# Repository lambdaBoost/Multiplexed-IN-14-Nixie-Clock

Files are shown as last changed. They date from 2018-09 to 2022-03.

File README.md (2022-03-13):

# Multiplexed IN-14 Nixie Clock
PCB design and coding for a slimline nixie clock using multiplexing of 6 IN-14 nixie tubes. Powered by a standard Micro USB.

[*Youtube video discussing principles of operation and showing it in action*](https://www.youtube.com/watch?v=PkoFvk80PU8)

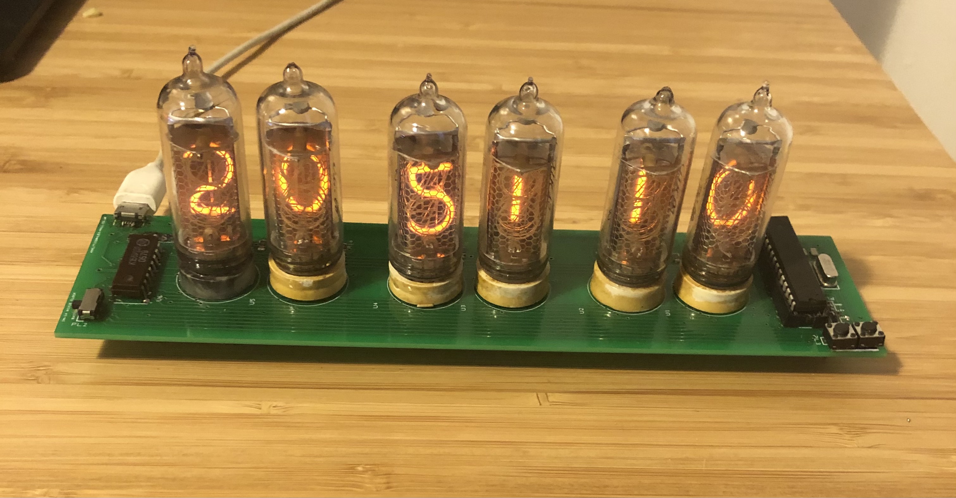
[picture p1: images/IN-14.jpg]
Prototype Build


## Principle of Operation.
This clock uses a Soviet-era Nixie driver to drive 6 Soviet-era Nixie tubes. The aim of this project was to produce a slimline and aesthetically pleasing clock for a minimal cost. To achieve this, the tubes are multiplexed meaning only a single driver chip is required. Multiplexing is not complicated - it is simply the act of switching the tubes on and off at a high enough frequency that the human eye cannot detect the flicker. By only having one tube on at a given time, only one driver chip is needed, less microprocessor pins are needed and the power consumption is reduced.

Rather than attempting to rectify mains voltage, the unit is powered from a +5V USB. While less efficient, this removes the danger of dealing with mains voltage.

## How to build your own
For those wanting to just build a clock and not worry about the details, just follow these steps:

* Gather materials given in the bill of materials (in the PCB design folder).
* Gather the additional materials listed below.
* Have the PCB manufactured with the gerber files provided. You'll need to choose whether to go with the original pcb design which has some issues, or the rev2 where these are fixed but it's untested.
* Solder the components to the PCB. Be careful with the nixie tubes - let them cool down between soldering each pin.
* Upload either the software_rtc.ino' script to your Arduino Uno if you don't have an rtc module installed. If you did but an rtc module, upload the 'hardware_rtc.ino' script.
* Remove the chip from the Arduino and insert into the socket on the pcb.
* Plug in a microUSB and set the time using the buttons. Push both to reset the seconds, and hold both to adjust the brightness.

## PCB design

**Note there are two seperate designs - the original and the rev 2. The original is tested and pictured above sitting on my desk (with some minor modifications to connect the buttons and add decoupling capacitors and add a switch which was not included on the original schematic). The rev 2 fixes some issues discussed below but I have not had this version manufactured so it is currently untested but should work fine providing I didn't make any mistakes fixing up the issues.**

The 'PCB design' directory contains all the files necessary for production of the PCB. For those just wanting to make the clock, the gerber files alone are sufficient - they can be sent to your PCB manufacturer of choice.

For anyone wanting to improve on the design, which is not perfect, the sehematic and PCB files are also included.

The bill of materials is also included. In addition to the components stated, you will need:
* 6 X IN-14 nixie tubes 
* a single K155ID1 nixie driver. A 74141 driver may also be used but these are rare/expensive and offer no real benefit over the former (the K155ID1 is a Russian copy of the 74141). 
* A nixie power supply. One that can provide 170V from a 5V DC source is necessary - plenty are available online but check the order of the output pins - the one I used was cheap but seems to work fine for now. It is available [here]( https://bit.ly/2IDABvU).  
* (OPTIONAL). If you want the clock to keep time when it is unplugged you'll need a DS1307 RTC module like [this](https://www.amazon.co.uk/DS1307-AT24C32-Clock-module-board/dp/B00CWX6UXY). Again, check that the pins are in the same order as that shown. You need them in the order GND,VCC,SDA,SCL. If you want more accurate timekeeping, a DS3231 would be better but you'll have to make a couple of monir changes to the code.
* A USB -> micro USB cable to power it.
* Either an Arduino UNO, or a ISP capable of programming the Atmega328p chip.

It would be possible to reduce the profile of the PCB further by using a SMD microprocessor and an alternate driver chip for the tubes. However, the configuration used here is far easier to program and install. I also personally like the aesthetics of the DIP chips next to the Nixie tubes.

## Arduino code
As the unit uses an ATMEGA328p DIP chip, it can be programmed using an arduino UNO. Simply upload the code to your UNO, remove the DIP chip and insert it into the holder on the PCB - that's it, no ISP programmer needed.

The code required depends on whether you have a DS1307 (or other RTC) module installed:
* If you have a ds1307 module installed, upload the code at nixie_code/hardware_rtc
* If you don't, upload the code at nixie_code/software_rtc

I won't go into details here since the code is commented.

## Improvements
As I designed this PCB a few years ago, and I'm not an electronics engineer, it has some issues which I should really fix. I'll keep these updated in the project issues.

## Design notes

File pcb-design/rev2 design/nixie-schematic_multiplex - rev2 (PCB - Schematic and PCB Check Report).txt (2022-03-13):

Schematic and PCB Check Report
------------------------------

Report Written:     Sunday, March 13, 2022
Design Path:        C:\Users\Alex\Documents\personal-projects\Multiplexed-IN-14-Nixie-Clock\pcb-design\rev2 design\nixie-schematic_multiplex - rev2.pcb
Design Title:       
Created:            13/09/2018 13:02:49
Last Saved:         13/03/2022 22:27:51
Editing Time:       9024 min
Units:              mm (precision 1)

Checking integrity of Schematic "C:\Users\Alex\Documents\personal-projects\Multiplexed-IN-14-Nixie-Clock\pcb-design\rev2 design\nixie-schematic_multiplex - rev2.sch" with PCB "C:\Users\Alex\Documents\personal-projects\Multiplexed-IN-14-Nixie-Clock\pcb-design\rev2 design\nixie-schematic_multiplex - rev2.pcb"
====================================================================================================================================================================================================================================================================================================================

End Of Report.

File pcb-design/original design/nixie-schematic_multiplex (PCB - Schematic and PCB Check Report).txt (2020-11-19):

Schematic and PCB Check Report
------------------------------

Report Written:     Thursday, November 19, 2020
Design Path:        C:\Users\Alex\Documents\personal-projects\Multiplexed-IN-14-Nixie-Clock\pcb-design\original design\nixie-schematic_multiplex.pcb
Design Title:       
Created:            13/09/2018 13:02:49
Last Saved:         19/11/2020 09:54:43
Editing Time:       8970 min
Units:              mm (precision 1)

Checking integrity of Schematic "C:\Users\Alex\Documents\personal-projects\Multiplexed-IN-14-Nixie-Clock\pcb-design\original design\nixie-schematic_multiplex.sch" with PCB "C:\Users\Alex\Documents\personal-projects\Multiplexed-IN-14-Nixie-Clock\pcb-design\original design\nixie-schematic_multiplex.pcb"
==============================================================================================================================================================================================================================================================================================================

End Of Report.

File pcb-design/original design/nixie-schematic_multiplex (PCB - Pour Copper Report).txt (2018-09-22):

Pour Copper Report
------------------

Report Written:     Tuesday, September 18, 2018
Design Path:        C:\Users\ahall\Documents\projects\nixie-clock\nixie-clock\designspark-nixie\nixie-schematic_multiplex2.pcb
Design Title:       
Created:            13/09/2018 14:02:49
Last Saved:         18/09/2018 20:24:57
Editing Time:       7505 min
Units:              mm (precision 1)

End Of Report.

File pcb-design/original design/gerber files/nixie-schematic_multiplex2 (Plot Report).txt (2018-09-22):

Plot Report
-----------

Report Written:     Monday, September 17, 2018
Design Path:        C:\Users\ahall\Documents\projects\nixie-clock\nixie-clock\designspark-nixie\nixie-schematic_multiplex2.pcb
Design Title:       
Created:            13/09/2018 14:02:49
Last Saved:         17/09/2018 21:49:33
Editing Time:       6154 min
Units:              mm (precision 1)

Device Settings
===============

Gerber Settings
===============

    Leading zero suppression.
    G01 assumed throughout.
    Line termination <*> <CR> <LF>.
    3.5 format absolute inches.

    Format commands defined in Gerber file.
    Aperture table defined in Gerber file.
    Hardware arcs allowed.

Drill Settings
==============

    Excellon Format 1    Format 3.5 absolute in inches.
    Leading zero suppression.

Plots Output
============

Gerber Output
=============

C:\Users\ahall\Documents\projects\nixie-clock\nixie-clock\designspark-nixie\nixie-schematic_multiplex2 - Top Documentation.gbr

    Layers:
    ---------------------
    Top Documentation

    D-Code Shape  (thou)
    -----------------------
    D10    Round 1.97

Gerber Output
=============

C:\Users\ahall\Documents\projects\nixie-clock\nixie-clock\designspark-nixie\nixie-schematic_multiplex2 - Top Silkscreen.gbr

    Layers:
    ------------------
    Top Silkscreen

    D-Code Shape  (thou)
    -----------------------
    D12    Round 1.00
    D14    Round 7.87
    D15    Round 5.00
    D16    Round 10.00

Gerber Output
=============

C:\Users\ahall\Documents\projects\nixie-clock\nixie-clock\designspark-nixie\nixie-schematic_multiplex2 - Top Copper.gbr

    Layers:
    --------------
    Top Copper

    D-Code Shape  (thou)
    ----------------------------------------------
    D18    Square 44.61
    D19    Round 44.61
    D71    Square 60.00
    D20    Round 44.49
    D25    Round 60.00
    D27    Round 56.00
    D28    Round 50.00
    D29    Round 48.00
    D72    Round 15.00
    D86    Oval 60.00 X 110.00  Rotation 90
    D87    Rectangle 23.62 X 41.34  Rotation 90
    D88    Rectangle 27.56 X 39.37
    D89    Rectangle 45.28 X 66.93
    D90    Rectangle 39.37 X 68.90
    D91    Rectangle 15.75 X 53.15  Rotation 90
    D92    Rectangle 47.24 X 51.18  Rotation 90
    D93    Rectangle 74.80 X 84.65
    D94    Rectangle 40.16 X 71.65
    D95    Rectangle 41.34 X 70.87  Rotation 90

Gerber Output
=============

C:\Users\ahall\Documents\projects\nixie-clock\nixie-clock\designspark-nixie\nixie-schematic_multiplex2 - Top Copper (Resist).gbr

    Layers:
    --------------
    Top Copper

    D-Code Shape  (thou)
    ----------------------------------------------
    D73    Square 54.61
    D74    Round 54.61
    D76    Square 70.00
    D77    Round 54.49
    D82    Round 70.00
    D96    Oval 70.00 X 120.00  Rotation 90
    D97    Rectangle 33.62 X 51.34  Rotation 90
    D98    Rectangle 37.56 X 49.37
    D99    Rectangle 55.28 X 76.93
    D100   Rectangle 49.37 X 78.90
    D101   Rectangle 25.75 X 63.15  Rotation 90
    D102   Rectangle 57.24 X 61.18  Rotation 90
    D103   Rectangle 84.80 X 94.65
    D104   Rectangle 50.16 X 81.65
    D105   Rectangle 51.34 X 80.87  Rotation 90

Gerber Output
=============

C:\Users\ahall\Documents\projects\nixie-clock\nixie-clock\designspark-nixie\nixie-schematic_multiplex2 - Top Copper (Paste).gbr

    Layers:
    --------------
    Top Copper

    D-Code Shape  (thou)
    ----------------------------------------------
    D106   Rectangle 19.62 X 37.34  Rotation 90
    D107   Rectangle 23.56 X 35.37
    D108   Rectangle 41.28 X 62.93
    D109   Rectangle 35.37 X 64.90
    D110   Rectangle 11.75 X 49.15  Rotation 90
    D111   Rectangle 43.24 X 47.18  Rotation 90
    D112   Rectangle 70.80 X 80.65
    D113   Rectangle 36.16 X 67.65
    D114   Rectangle 37.34 X 66.87  Rotation 90

Gerber Output
=============

C:\Users\ahall\Documents\projects\nixie-clock\nixie-clock\designspark-nixie\nixie-schematic_multiplex2 - Bottom Copper.gbr

    Layers:
    -----------------
    Bottom Copper

    D-Code Shape  (thou)
    ------------------------------------------
    D18    Square 44.61
    D19    Round 44.61
    D71    Square 60.00
    D20    Round 44.49
    D25    Round 60.00
    D27    Round 56.00
    D28    Round 50.00
    D29    Round 48.00
    D72    Round 15.00
    D86    Oval 60.00 X 110.00  Rotation 90

Gerber Output
=============

C:\Users\ahall\Documents\projects\nixie-clock\nixie-clock\designspark-nixie\nixie-schematic_multiplex2 - Bottom Copper (Resist).gbr

    Layers:
    -----------------
    Bottom Copper

    D-Code Shape  (thou)
    ------------------------------------------
    D73    Square 54.61
    D74    Round 54.61
    D76    Square 70.00
    D77    Round 54.49
    D82    Round 70.00
    D96    Oval 70.00 X 120.00  Rotation 90

Gerber Output
=============

C:\Users\ahall\Documents\projects\nixie-clock\nixie-clock\designspark-nixie\nixie-schematic_multiplex2 - Bottom Copper (Paste).gbr

    Layers:
    -----------------
    Bottom Copper

    D-Code Shape  (thou)
    -----------------------

NC Drill Output
===============

C:\Users\ahall\Documents\projects\nixie-clock\nixie-clock\designspark-nixie\nixie-schematic_multiplex2 - Drill Data - [Through Hole].drl

    Output:
    ---------------------------
    Plated Round Drill Holes
    Plated Slots
    Plated Board Outlines

    Tool  Size           Count   ID
    --------------------------------------
    T001  0.02400 inches 128   K
    T002  0.02480 inches 2     D
    T003  0.02886 inches 44    A
    T004  0.03200 inches 35    J
    T005  0.03500 inches 12    C
    T006  0.03543 inches 78    H
    --------------------------------------
    Total                299
    --------------------------------------

C:\Users\ahall\Documents\projects\nixie-clock\nixie-clock\designspark-nixie\nixie-schematic_multiplex2 - Drill Data - [Through Hole] (Unplated).drl

    Output:
    -----------------------------
    Unplated Round Drill Holes
    Unplated Slots
    Unplated Board Outlines

    Tool  Size           Count   ID
    --------------------------------------
    T001  0.02500 inches 1
    --------------------------------------
    Total                1
    --------------------------------------

Gerber Output
=============

C:\Users\ahall\Documents\projects\nixie-clock\nixie-clock\designspark-nixie\nixie-schematic_multiplex2 - outline.gbr

    Layers:
    ------------------
    Board Outlines

    D-Code Shape  (thou)
    -----------------------
    D15    Round 5.00

End Of Report.

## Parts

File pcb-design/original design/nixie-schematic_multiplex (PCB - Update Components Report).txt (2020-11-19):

Update Components Report
------------------------

Report Written:     Thursday, November 19, 2020
Design Path:        C:\Users\Alex\Documents\personal-projects\Multiplexed-IN-14-Nixie-Clock\pcb-design\original design\nixie-schematic_multiplex.pcb
Design Title:       
Created:            13/09/2018 13:02:49
Last Saved:         19/11/2020 09:55:28
Editing Time:       8971 min
Units:              mm (precision 1)

Library Files:
==============

C:\Users\Alex\Documents\DesignSpark PCB 9.0\Library\User\User.cml
C:\Users\Alex\Documents\DesignSpark PCB 9.0\Library\Default\DesignSpark.cml
C:\Users\Alex\Documents\DesignSpark PCB 9.0\Library\Default\ltspice.cml
C:\Users\Alex\Documents\DesignSpark PCB 9.0\Library\Default\XSpice.cml

Selected items to be updated:
=============================

Components:
===========

SN74141 (DIP787W53P279L2176H508Q16N)

Symbols:
========

    (None) 

Additional items to be updated:
===============================

Components:
===========

    (None) 

Symbols:
========

    (None) 

Selected items not to be updated  (Same version as library)
===========================================================

Components:
===========

    (None) 

Symbols:
========

DIP787W53P279L2176H508Q16N C:\Users\Alex\Documents\DesignSpark PCB 9.0\Library\User\User.psl

Errors accessing items in the library:
======================================

Components:
===========

    Could not find component 'SN74141' package 'DIP787W53P279L2176H508Q16N'

Update Components Summary
=========================

Updating single component.
Keep component values
Keep component value positions
(Remove pad style exceptions on updated components)
	Selected for update:			   1  Component 
						   1  Symbol 
	Selected items to be updated:		   1  Component 
						   0  Symbols
	Additional items to be updated:		   0  Components
						   0  Symbols
	Selected items NOT to be updated:	   0  Components
	  (Same version as library)		   1  Symbol 
Errors getting items from the library:		   1  Component 
	  (Not found or read error)			   0  Symbols

End Of Report.

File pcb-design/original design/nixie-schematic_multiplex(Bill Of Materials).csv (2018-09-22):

Report Written: | Monday, September 17, 2018
Design Path: | C:\Users\ahall\Documents\projects\nixie-clock\nixie-clock\designspark-nixie\nixie-schematic_multiplex2.sch
Design Title:
Created:
Last Saved: | 14/09/2018 23:08:24
Editing Time: | 10723 min
Units: | thou (precision 2)
Bill of Materials generated with DesignSpark PCB - www.DesignSpark.com/pcb
--------------------------------------------------------------------------
Ref Name | Qty | Component | Value | Package | Manufacturer | MPN | RS Part Number | Other Part Number | Description
REF1 | 1 | +5V |  |  |  |  |  |  | Power
REF2 | 1 | +5V |  |  |  |  |  |  | Power
REF6 | 1 | +5V |  |  |  |  |  |  | Power
REF49 | 1 | +5V |  |  |  |  |  |  | Power
REF20 | 1 | +5V |  |  |  |  |  |  | Power
REF21 | 1 | +5V |  |  |  |  |  |  | Power
REF9 | 1 | +5V |  |  |  |  |  |  | Power
PL1 | 1 | 4WP |  | DSC |  |  |  |  | 4 way Pin Header
PL2 | 1 | 4WP |  | DSC |  |  |  |  | 4 way Pin Header
PL3 | 1 | 4WP |  | DSC |  |  |  |  | 4 way Pin Header
IC1 | 1 | ATMEGA328-PU |  | DIP1016W53P254L3468H457Q28N | Microchip | ATMEGA328-PU |  |  | 8-bit Microcontrollers - MCU AVR 32K FLSH 1K EE2K SRAM-20MHz IND
C1 | 1 | C1206C200J5GACTU |  | CAPC3216X88N | Kemet | C1206C200J5GACTU | 8702877 |  | Kemet 1206 C 20pF Ceramic Multilayer Capacitor, 50 V dc, +125C, C0G Dielectric, 5%
C2 | 1 | C1206C200J5GACTU |  | CAPC3216X88N | Kemet | C1206C200J5GACTU | 8702877 |  | Kemet 1206 C 20pF Ceramic Multilayer Capacitor, 50 V dc, +125C, C0G Dielectric, 5%
R20 | 1 | CRCW120610K2FKEA |  | RESC3216X60N | Vishay | CRCW120610K2FKEA |  |  | RESISTOR, 1206 10.2K Ohms 1% 0.25W
J1 | 1 | DX4R005HJ5R2000 |  | DX4R005HJ5 | JAE Electronics | DX4R005HJ5R2000 |  |  | USB Connectors microUSB 2.0 TYPE B STDMNT RCPT NO TAPER
R2 | 1 | ERA-8AEB105V |  | RESC3216X70N | Panasonic | ERA-8AEB105V |  |  | Thin Film Resistors - SMD 1206 1.0Mohm 0.1% 25ppm
R5 | 1 | ERA-8AEB105V |  | RESC3216X70N | Panasonic | ERA-8AEB105V |  |  | Thin Film Resistors - SMD 1206 1.0Mohm 0.1% 25ppm
R9 | 1 | ERA-8AEB105V |  | RESC3216X70N | Panasonic | ERA-8AEB105V |  |  | Thin Film Resistors - SMD 1206 1.0Mohm 0.1% 25ppm
R12 | 1 | ERA-8AEB105V |  | RESC3216X70N | Panasonic | ERA-8AEB105V |  |  | Thin Film Resistors - SMD 1206 1.0Mohm 0.1% 25ppm
R15 | 1 | ERA-8AEB105V |  | RESC3216X70N | Panasonic | ERA-8AEB105V |  |  | Thin Film Resistors - SMD 1206 1.0Mohm 0.1% 25ppm
R18 | 1 | ERA-8AEB105V |  | RESC3216X70N | Panasonic | ERA-8AEB105V |  |  | Thin Film Resistors - SMD 1206 1.0Mohm 0.1% 25ppm
R1 | 1 | ERA-8AEB272V |  | RESC3216X70N | Panasonic | ERA-8AEB272V |  |  | Thin Film Resistors - SMD 1206 2.7Kohm 0.1% 25ppm
R4 | 1 | ERA-8AEB272V |  | RESC3216X70N | Panasonic | ERA-8AEB272V |  |  | Thin Film Resistors - SMD 1206 2.7Kohm 0.1% 25ppm
R7 | 1 | ERA-8AEB272V |  | RESC3216X70N | Panasonic | ERA-8AEB272V |  |  | Thin Film Resistors - SMD 1206 2.7Kohm 0.1% 25ppm
R11 | 1 | ERA-8AEB272V |  | RESC3216X70N | Panasonic | ERA-8AEB272V |  |  | Thin Film Resistors - SMD 1206 2.7Kohm 0.1% 25ppm
R14 | 1 | ERA-8AEB272V |  | RESC3216X70N | Panasonic | ERA-8AEB272V |  |  | Thin Film Resistors - SMD 1206 2.7Kohm 0.1% 25ppm
R17 | 1 | ERA-8AEB272V |  | RESC3216X70N | Panasonic | ERA-8AEB272V |  |  | Thin Film Resistors - SMD 1206 2.7Kohm 0.1% 25ppm
Y1 | 1 | FOXSLF_160-20 |  | HC49SLF_1 | Fox | FOXSLF/160-20 | 1734298 |  | Crystal 16.000MHz HC49S HC-49-SLF Crystal 16MHz, ??30ppm, 2-Pin
REF4 | 1 | GND |  |  |  |  |  |  | Power
REF8 | 1 | GND |  |  |  |  |  |  | Power
REF5 | 1 | GND |  |  |  |  |  |  | Power
REF36 | 1 | GND |  |  |  |  |  |  | Power
REF37 | 1 | GND |  |  |  |  |  |  | Power
REF13 | 1 | GND |  |  |  |  |  |  | Power
REF14 | 1 | GND |  |  |  |  |  |  | Power
REF15 | 1 | GND |  |  |  |  |  |  | Power
REF16 | 1 | GND |  |  |  |  |  |  | Power
REF17 | 1 | GND |  |  |  |  |  |  | Power
REF18 | 1 | GND |  |  |  |  |  |  | Power
REF19 | 1 | GND |  |  |  |  |  |  | Power
REF11 | 1 | GND |  |  |  |  |  |  | Power
REF3 | 1 | GND |  |  |  |  |  |  | Power
REF7 | 1 | GND |  |  |  |  |  |  | Power
REF10 | 1 | GND |  |  |  |  |  |  | Power
H1 | 1 | Header (5 pole) |  | DIL
U1 | 1 | IN-14 Nixie |  | USER
U2 | 1 | IN-14 Nixie |  | USER
U3 | 1 | IN-14 Nixie |  | USER
U4 | 1 | IN-14 Nixie |  | USER
U5 | 1 | IN-14 Nixie |  | USER
U6 | 1 | IN-14 Nixie |  | USER
IC5 | 1 | KST42MTF |  | SOT95P240X120-3N | Fairchild Semiconductor | KST42MTF | 6711147 |  | Trans GP BJT NPN 300V 0.5A 3-Pin SOT-23 Fairchild KST42MTF NPN High Voltage Bipolar Transistor, 0.5 A 300 V, 3-Pin SOT-23
IC4 | 1 | KST42MTF |  | SOT95P240X120-3N | Fairchild Semiconductor | KST42MTF | 6711147 |  | Trans GP BJT NPN 300V 0.5A 3-Pin SOT-23 Fairchild KST42MTF NPN High Voltage Bipolar Transistor, 0.5 A 300 V, 3-Pin SOT-23
IC3 | 1 | KST42MTF |  | SOT95P240X120-3N | Fairchild Semiconductor | KST42MTF | 6711147 |  | Trans GP BJT NPN 300V 0.5A 3-Pin SOT-23 Fairchild KST42MTF NPN High Voltage Bipolar Transistor, 0.5 A 300 V, 3-Pin SOT-23
IC6 | 1 | KST42MTF |  | SOT95P240X120-3N | Fairchild Semiconductor | KST42MTF | 6711147 |  | Trans GP BJT NPN 300V 0.5A 3-Pin SOT-23 Fairchild KST42MTF NPN High Voltage Bipolar Transistor, 0.5 A 300 V, 3-Pin SOT-23
IC7 | 1 | KST42MTF |  | SOT95P240X120-3N | Fairchild Semiconductor | KST42MTF | 6711147 |  | Trans GP BJT NPN 300V 0.5A 3-Pin SOT-23 Fairchild KST42MTF NPN High Voltage Bipolar Transistor, 0.5 A 300 V, 3-Pin SOT-23
IC8 | 1 | KST42MTF |  | SOT95P240X120-3N | Fairchild Semiconductor | KST42MTF | 6711147 |  | Trans GP BJT NPN 300V 0.5A 3-Pin SOT-23 Fairchild KST42MTF NPN High Voltage Bipolar Transistor, 0.5 A 300 V, 3-Pin SOT-23
Q3 | 1 | PMBTA92,215 |  | SOT95P230X110-3N | Nexperia | PMBTA92,215 |  |  | PMBTA92 - PNP high-voltage transistor
Q2 | 1 | PMBTA92,215 |  | SOT95P230X110-3N | Nexperia | PMBTA92,215 |  |  | PMBTA92 - PNP high-voltage transistor
Q1 | 1 | PMBTA92,215 |  | SOT95P230X110-3N | Nexperia | PMBTA92,215 |  |  | PMBTA92 - PNP high-voltage transistor
Q4 | 1 | PMBTA92,215 |  | SOT95P230X110-3N | Nexperia | PMBTA92,215 |  |  | PMBTA92 - PNP high-voltage transistor
Q5 | 1 | PMBTA92,215 |  | SOT95P230X110-3N | Nexperia | PMBTA92,215 |  |  | PMBTA92 - PNP high-voltage transistor
Q6 | 1 | PMBTA92,215 |  | SOT95P230X110-3N | Nexperia | PMBTA92,215 |  |  | PMBTA92 - PNP high-voltage transistor
R3 | 1 | RC1206JR-0733KL |  | RESC3116X65N | YAGEO (PHYCOMP) | RC1206JR-0733KL |  |  | RESISTOR, 1206 33K Ohms 5% 1/4 W
R6 | 1 | RC1206JR-0733KL |  | RESC3116X65N | YAGEO (PHYCOMP) | RC1206JR-0733KL |  |  | RESISTOR, 1206 33K Ohms 5% 1/4 W
R10 | 1 | RC1206JR-0733KL |  | RESC3116X65N | YAGEO (PHYCOMP) | RC1206JR-0733KL |  |  | RESISTOR, 1206 33K Ohms 5% 1/4 W
R13 | 1 | RC1206JR-0733KL |  | RESC3116X65N | YAGEO (PHYCOMP) | RC1206JR-0733KL |  |  | RESISTOR, 1206 33K Ohms 5% 1/4 W
R16 | 1 | RC1206JR-0733KL |  | RESC3116X65N | YAGEO (PHYCOMP) | RC1206JR-0733KL |  |  | RESISTOR, 1206 33K Ohms 5% 1/4 W
R19 | 1 | RC1206JR-0733KL |  | RESC3116X65N | YAGEO (PHYCOMP) | RC1206JR-0733KL |  |  | RESISTOR, 1206 33K Ohms 5% 1/4 W
IC2 | 1 | SN74141 |  | DIP787W53P279L2176H508Q16N | Texas Instruments | SN74141 |  |  | Nixie driver
REF38 | 1 | Vcc |  |  |  |  |  |  | Power
REF12 | 1 | Vcc |  |  |  |  |  |  | Power

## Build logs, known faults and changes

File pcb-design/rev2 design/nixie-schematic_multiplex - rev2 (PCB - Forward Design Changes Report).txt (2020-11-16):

Forward Design Changes Report
-----------------------------

Report Written:     Monday, November 16, 2020
Design Path:        C:\Users\Alex\Documents\nixie-clock\pcb-design\rev2 design\nixie-schematic_multiplex - rev2.pcb
Design Title:       
Created:            13/09/2018 13:02:49
Last Saved:         16/11/2020 22:28:36
Editing Time:       9006 min
Units:              mm (precision 1)

Disconnected pin "S1.1" from net "+5v".
Disconnected pin "S1.3" from net "N0450".

Deleted net "N0450".

Added net "N0451".

Connected pin "S1.1" to net "N0451".

End Of Report.

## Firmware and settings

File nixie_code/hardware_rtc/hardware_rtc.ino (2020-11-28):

//TODO:
//if clock doesnt work try powering it from the analog pins (needs rewire to do this)
//add button support
//add anti-posion function

#include "RTClib.h"
#include <Wire.h>

int A = 3;
int B = 2;
int C = 1;
int D = 0;

int hrButton = 4;
int minButton = 5;


static int MULTIPLEX_DELAY = 2; //pulse width 2
int BLANKING_INTERVAL_OPTIONS[5] = {200,400,800,1600,2400};
int BLANKING_INTERVAL = BLANKING_INTERVAL_OPTIONS[0]; //microseconds 200
static long CYCLE_INTERVAL = 1000; //interval between changes for cathode poisoning prevention scheme
int num = 0; //start digit for cathode poisoning prevention
unsigned long previousMillis = 0;

//define rtc as either external module or internal
RTC_DS1307 rtc;
//RTC_Millis rtc2;

// 0 for digit test 1 for tube test
int mode = 0;

int hr;
int mn;
int sec;

int T1;
int T2;
int T3;
int T4;
int T5;
int T6;

void setup() {

  pinMode(A,OUTPUT);
  pinMode(B,OUTPUT);
  pinMode(C,OUTPUT);
  pinMode(D,OUTPUT);
  
  digitalWrite(A, LOW);
  digitalWrite(B, LOW);
  digitalWrite(C, LOW);
  digitalWrite(D, LOW);

  
  pinMode(hrButton, INPUT_PULLUP);
  pinMode(minButton, INPUT_PULLUP);
  
  //nixie anode pins
  pinMode(6,OUTPUT);
  pinMode(7,OUTPUT);
  pinMode(8,OUTPUT);
  pinMode(9,OUTPUT);
  pinMode(10,OUTPUT);
  pinMode(11,OUTPUT);

  if (! rtc.begin()) {
    abort();
  }

  //Set RTC start time as program upload time if RTC not running
  if (! rtc.isrunning()) {
  rtc.adjust(DateTime(F(__DATE__), F(__TIME__)));
  }


}


int previousHrButton = digitalRead(hrButton);
int previousMinButton = digitalRead(minButton);
int hrButtonState;
int minButtonState;


void loop() {

 DateTime tm = rtc.now();
 hr = tm.hour();
 mn = tm.minute();
 sec = tm.second();

 //run anti cathode poisoining for 1 hr at 2am (excessive but thats ok)
  if(hr ==2 or mode==1){
    antiPoison();
  }

  else{
  displayTime();
  }

  //handle button pushes
  //increment on button release so second zero doesnt affect hrs and mins
  //hold both for second zero
  hrButtonState = digitalRead(hrButton);
  minButtonState = digitalRead(minButton);

  if(hrButtonState == HIGH and previousHrButton == LOW and millis() > 500 ){
    incrementHour();
  }

  if(minButtonState == HIGH and previousMinButton == LOW and millis() > 500 ){
    incrementMinute();
  }

  if(minButtonState == LOW and hrButtonState ==LOW){
    delay(1000);
    hrButtonState = digitalRead(hrButton);
    minButtonState = digitalRead(minButton);
    if(minButtonState == HIGH or hrButtonState ==HIGH){

    zeroSeconds();
    }
  

    
    else{

      int x=1;


      //if both buttons held, change brightness
      while(minButtonState == LOW and hrButtonState ==LOW){

        displayTime();
        
        if(x>4){
          x = 0;
        }
        
        
        unsigned long currentMillis = millis();
        if(currentMillis - previousMillis >= CYCLE_INTERVAL){
        previousMillis = currentMillis;
        BLANKING_INTERVAL = BLANKING_INTERVAL_OPTIONS[x];
        x=x+1;
        }

        hrButtonState = digitalRead(hrButton);
        minButtonState = digitalRead(minButton);
      }

      // allow time to release both buttons
      delay(1000);

      previousMillis = 0;
      
    }
  }
  


  previousHrButton = digitalRead(hrButton);
  previousMinButton = digitalRead(minButton);

}





void displayDigit(int i){

  if(i==0){
  digitalWrite(A,LOW);
  digitalWrite(B,LOW);
  digitalWrite(C,LOW);
  digitalWrite(D,LOW);
  }
  
  if(i==1){
  digitalWrite(A,HIGH);
  digitalWrite(B,LOW);
  digitalWrite(C,LOW);
  digitalWrite(D,LOW);
  }
  
  if(i==2){
  digitalWrite(A,LOW);
  digitalWrite(B,HIGH);
  digitalWrite(C,LOW);
  digitalWrite(D,LOW);
  }
  

  if(i==3){
  digitalWrite(A,HIGH);
  digitalWrite(B,HIGH);
  digitalWrite(C,LOW);
  digitalWrite(D,LOW);
  }
  
  
  if(i==4){
  digitalWrite(A,LOW);
  digitalWrite(B,LOW);
  digitalWrite(C,HIGH);
  digitalWrite(D,LOW);
  }
  
  
  if(i==5){
  digitalWrite(A,HIGH);
  digitalWrite(B,LOW);
  digitalWrite(C,HIGH);
  digitalWrite(D,LOW);
  }
  
  
  if(i==6){
  digitalWrite(A,LOW);
  digitalWrite(B,HIGH);
  digitalWrite(C,HIGH);
  digitalWrite(D,LOW);
  }
  
  
  if(i==7){
  digitalWrite(A,HIGH);
  digitalWrite(B,HIGH);
  digitalWrite(C,HIGH);
  digitalWrite(D,LOW);
  }
  
  
  if(i==8){
  digitalWrite(A,LOW);
  digitalWrite(B,LOW);
  digitalWrite(C,LOW);
  digitalWrite(D,HIGH);
  }
  
  
  if(i==9){
  digitalWrite(A,HIGH);
  digitalWrite(B,LOW);
  digitalWrite(C,LOW);
  digitalWrite(D,HIGH);
  }



}


void displayTime(){

  //get decimal values for each tube
  
  T1 = (hr / 10) % 10;
  T2 = hr % 10;
  T3 = (mn / 10) % 10;
  T4 = mn % 10;
  T5 = (sec / 10) % 10;
  T6 = sec % 10;

  
      displayDigit(T1);
      digitalWrite(11, HIGH);
      delay(MULTIPLEX_DELAY);
      digitalWrite(11,LOW);
      delayMicroseconds(BLANKING_INTERVAL);
      displayDigit(T2);
      digitalWrite(10, HIGH);
      delay(MULTIPLEX_DELAY);
      digitalWrite(10,LOW);
      delayMicroseconds(BLANKING_INTERVAL);
      displayDigit(T3);
      digitalWrite(9, HIGH);
      delay(MULTIPLEX_DELAY);
      digitalWrite(9,LOW);
      delayMicroseconds(BLANKING_INTERVAL);
      displayDigit(T4);
      digitalWrite(8, HIGH);
      delay(MULTIPLEX_DELAY);
      digitalWrite(8,LOW);
      delayMicroseconds(BLANKING_INTERVAL);
      displayDigit(T5);
      digitalWrite(7, HIGH);
      delay(MULTIPLEX_DELAY);
      digitalWrite(7,LOW);
      delayMicroseconds(BLANKING_INTERVAL);
      displayDigit(T6);
      digitalWrite(6, HIGH);
      delay(MULTIPLEX_DELAY);
      digitalWrite(6,LOW);
      delayMicroseconds(BLANKING_INTERVAL);

 
}



void incrementHour(){

  rtc.adjust( rtc.now() + 3600 ) ;
}


void incrementMinute(){

  rtc.adjust( rtc.now() + 60 ) ;
}


void zeroSeconds(){

  DateTime nw = rtc.now();
  int yr = nw.year();
  int mm = nw.month();
  int da = nw.day();
  int hr = nw.hour();
  int mn = nw.minute();
  int sec = 0;
  
  rtc.adjust(DateTime(yr, mm, da, hr, mn, sec)); //Set the RTC time to the new updated time
}


//cycle all digits to mitigate cathode poisoning
void antiPoison(){
  
  unsigned long currentMillis = millis();

  if (currentMillis - previousMillis >= CYCLE_INTERVAL) {
    previousMillis = currentMillis;
    num = num+1;

    if(num >9){
      num = 0;
    }
  }

  else{
      displayDigit(num);
      digitalWrite(6, HIGH);
      delay(MULTIPLEX_DELAY);
      digitalWrite(6,LOW);
      digitalWrite(7, HIGH);
      delay(MULTIPLEX_DELAY);
      digitalWrite(7,LOW);
      digitalWrite(8, HIGH);
      delay(MULTIPLEX_DELAY);
      digitalWrite(8,LOW);
      digitalWrite(9, HIGH);
      delay(MULTIPLEX_DELAY);
      digitalWrite(9,LOW);
      digitalWrite(10, HIGH);
      delay(MULTIPLEX_DELAY);
      digitalWrite(10,LOW);
      digitalWrite(11, HIGH);
      delay(MULTIPLEX_DELAY);
      digitalWrite(11,LOW);
  }

}

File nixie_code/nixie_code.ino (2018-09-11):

//TODO:
//if clock doesnt work try powering it from the analog pins (needs rewire to do this)
//add button support
//add anti-posion function

#include <ShiftRegister74HC595.h>
#include <RTClib.h>
#include <RealTimeClockDS1307.h>
#include <Wire.h>

// create shift register objectS (number of shift registers, SER pin, SRCLK pin, RCLK pin)
ShiftRegister74HC595 srH (1, 8, 9, 10); 
ShiftRegister74HC595 srM (1, 5, 6, 7); 
ShiftRegister74HC595 srS (1, 2, 3, 4); 

RTC_DS1307 rtc;

void setup() {
  
   //use internal pullup resistor for button.
  pinMode(1 , INPUT_PULLUP)
  
  //set the clock up
  Serial.begin(9600);
  delay(2000); //give the clock a chance to be read

}

void loop() {
  // put your main code here, to run repeatedly:
  DateTime now =rtc.now();

  setTubePair(srH , now.hour());
  setTubePair(srM , now.minute());
  setTubePair(srS, now.second());

}

// function to display two digits on a given shift registers nixies
void setTubePair(ShiftRegister74HC595 sr , int number_pair){
  
  //decimal numbers to display on each nixie
  int tube_1 = (number_pair ) % 10;
  int tube_2 = (number_pair / 10U) % 10;

  //passing binary of the desired decimal for a tube to its 74141 to pins DCBA causes it to output the desired digit
  // most significant bit goes to pin D and least significant to A (contrary to what we may guess)
  int sr_A = bitRead(tube_1 , 0); //least significant digit
  int sr_B = bitRead(tube_1 , 1);
  int sr_C = bitRead(tube_1 , 2);
  int sr_D = bitRead(tube_1 , 3);
  int sr_E = bitRead(tube_2 , 0);
  int sr_F = bitRead(tube_2 , 1);
  int sr_G = bitRead(tube_2 , 2);
  int sr_H = bitRead(tube_2 , 3);

  sr.set(0,sr_A);
  sr.set(1,sr_B);
  sr.set(2,sr_C);
  sr.set(3,sr_D);
  sr.set(4,sr_E);
  sr.set(5,sr_F);
  sr.set(6,sr_G);
  sr.set(7,sr_H);
} 

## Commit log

2018-09-10 optimised pcb routing
    [nixie-schematic.sch, nixie-schematic_manual.sch, ~nixie-schematic.sch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]
2018-09-11 added arduino script
    [nixie-schematic_manual (Bill Of Materials).csv, ~nixie-schematic_manual.sch]
2018-09-12 further pcb optimisation
    [nixie-schematic_manual (Bill Of Materials).csv, nixie-schematic_manual.sch, nixie-schematic_slimline.sch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]
2018-09-14 added pcb for multiplexed circuit
    [nixie-schematic_multiplex.sch, nixie-schematic_multiplex2.sch, nixie-schematic_slimline.sch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]
2018-09-22 added script for multiplexed clock
    [nixie-schematic_multiplex2 (Bill Of Materials).csv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]
2020-11-11 added multiplex test and fixed clock test script
    [~nixie-schematic_multiplex2.sch]
2020-11-12 added working clock script (without RTC module support for now)
    [~nixie-schematic_multiplex2.sch]
2020-11-12 added push button support
2020-11-14 tidied directories
    [nixie-schematic.sch, nixie-schematic_manual (Bill Of Materials).csv, nixie-schematic_manual.sch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]
2020-11-15 added test mode
    [~nixie-schematic_multiplex.sch]
2020-11-16 added decoupling caps and through hole connector to PCB
    [nixie-schematic_multiplex - rev2.sch, nixie-schematic_multiplex(Bill Of Materials).csv, nixie-schematic_multiplex.sch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]
2020-11-16 added proper power switch
    [nixie-schematic_multiplex - rev2.sch]
2020-11-17 Added optimal anode resistors
    [nixie-schematic_multiplex - rev2.sch, nixie-schematic_multiplex.sch]
2020-11-18 added PWM dimming
2020-11-19 Revised pin spacings
    [nixie-schematic_multiplex.sch]
2020-11-22 fixed rtc time adjustment issues
    [hardware_rtc.ino, nixie_code.ino]
2020-11-22 corrected startup hour-minute adjust bug
    [hardware_rtc.ino]
2022-03-13 fixed power switch and button issues in revised pcb design
